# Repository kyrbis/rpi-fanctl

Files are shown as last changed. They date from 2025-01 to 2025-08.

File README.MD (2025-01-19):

This is a replacement pcb for the [ElectroCookie Raspberry Pi 4 Case, Aluminum Mini Tower Case](https://www.amazon.de/dp/B09R6TZCQ8) (or probably [this one](https://www.amazon.de/dp/B09QG349ZL)) to be used with PWM controlled 5V fans like [noctua NF-A4x10 5V PWM, 4-Pin](https://www.amazon.de/dp/B07DXS86G7).

You might also need a [3D printed fan adapter](https://www.thingiverse.com/thing:2995904).

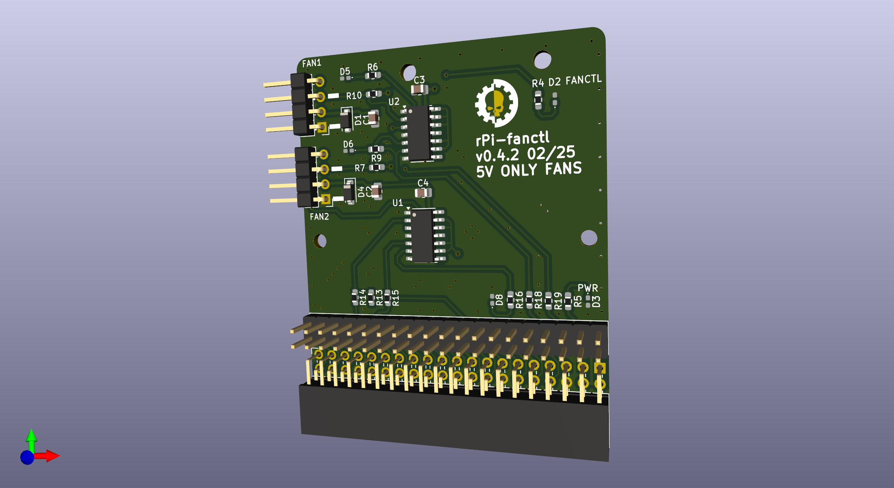
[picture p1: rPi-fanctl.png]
Blessed be the machine.


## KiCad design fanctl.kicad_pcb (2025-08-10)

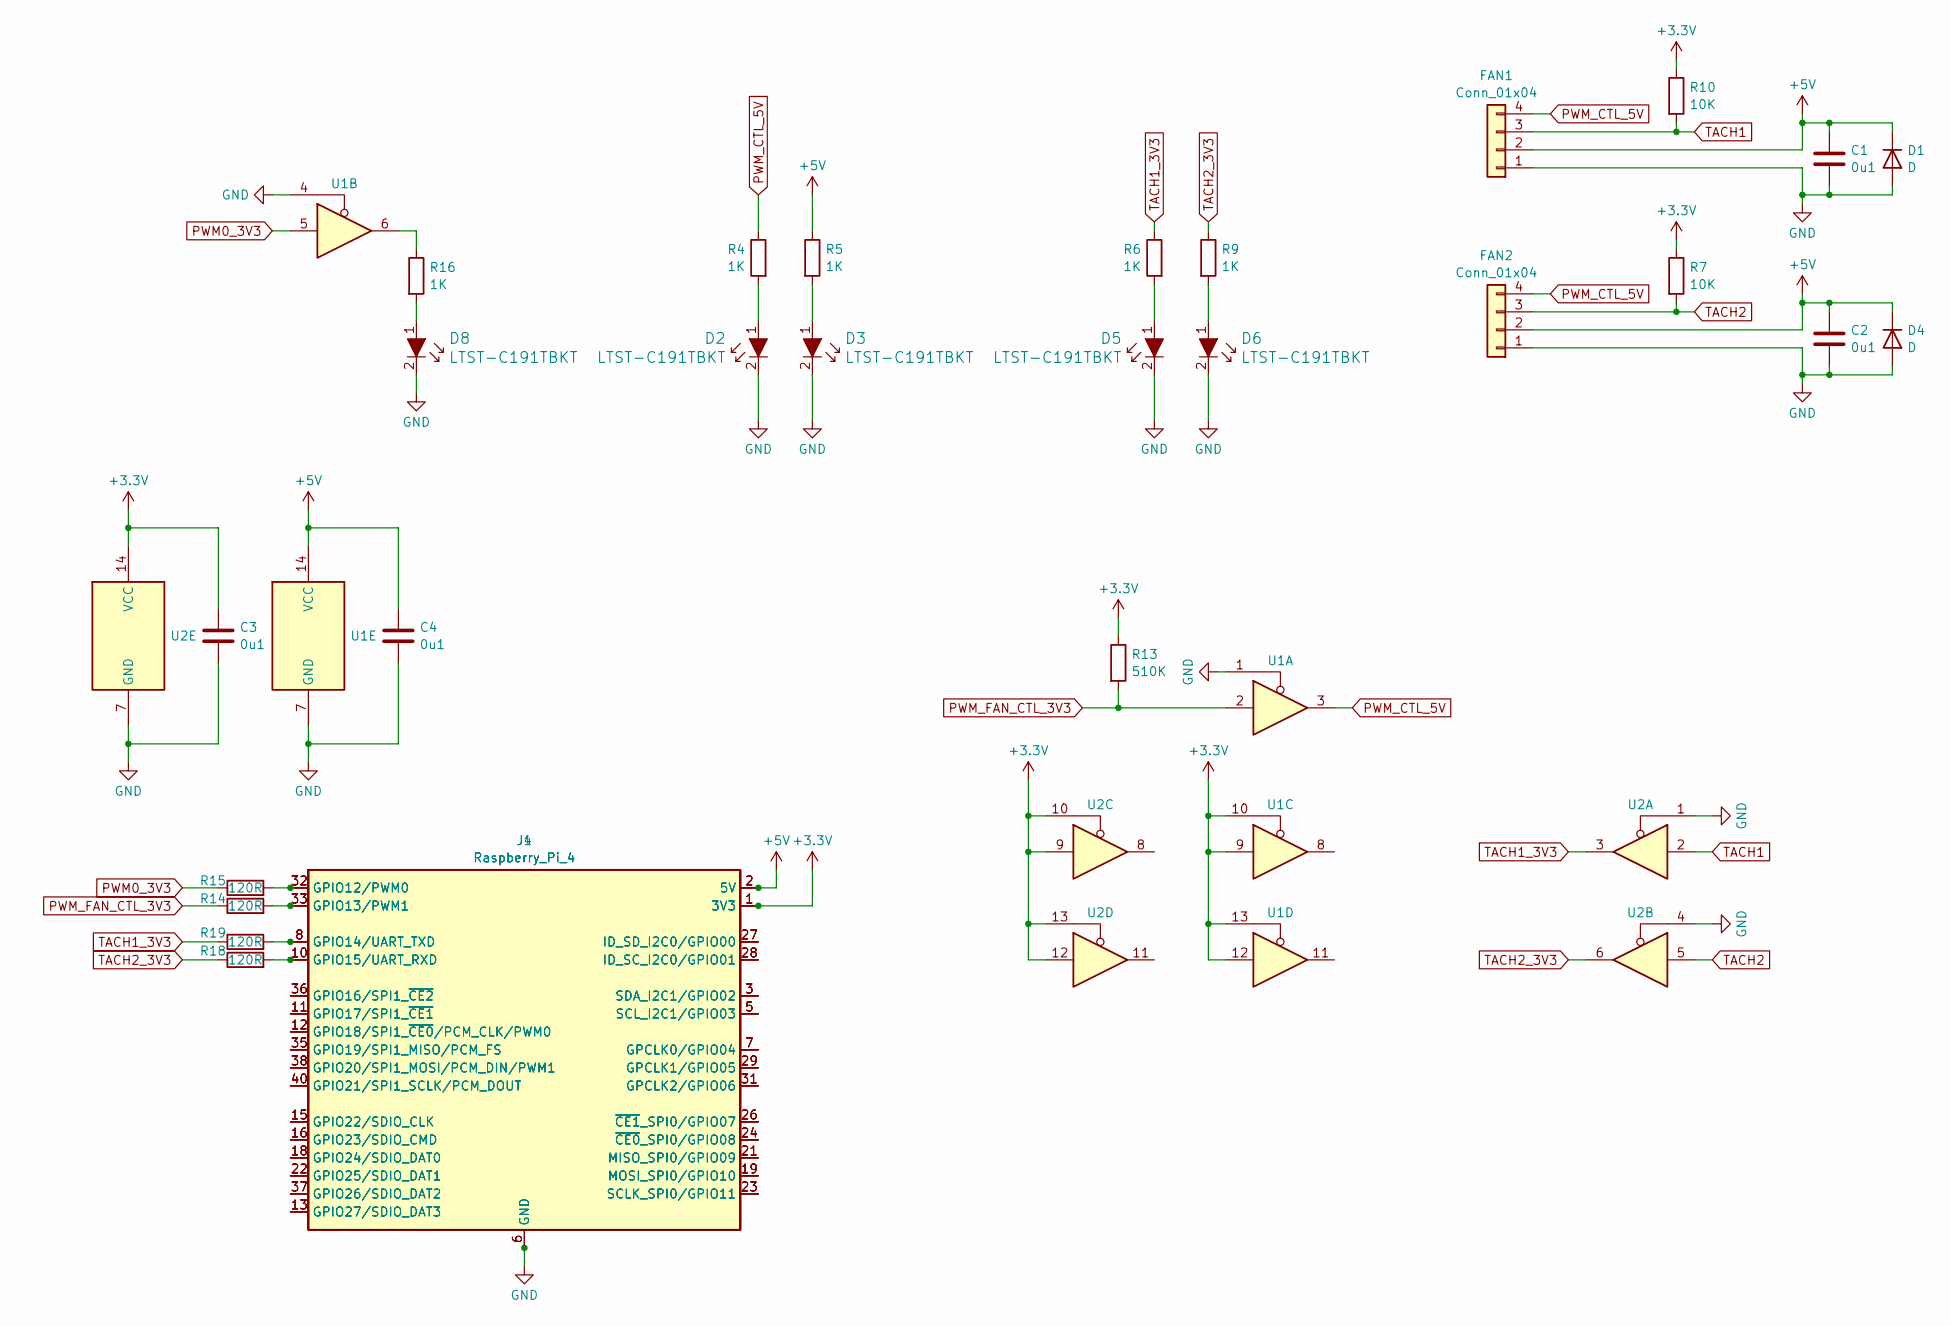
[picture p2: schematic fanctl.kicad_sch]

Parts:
C1, C2, C3, C4: 0u1; C_0805_2012Metric
D1: D; D_SOD-123F
D2, D3, D5, D6, D8: LTST-C191TBKT; D_0402_1005Metric_Pad0.77x0.64mm_HandSolder; MPN LTST-C191TBKT; Digi-Key_PN 160-1647-1-ND
D4: D; D_SOD-123
FAN1, FAN2: Conn_01x04; PinHeader_1x04_P2.54mm_Horizontal
J1: Raspberry_Pi_4; PinSocket_2x20_P2.54mm_Horizontal
J4: Raspberry_Pi_4; PinHeader_2x20_P2.54mm_Vertical
R4, R5, R6, R9, R16: 1K; R_0603_1608Metric_Pad0.98x0.95mm_HandSolder
R7, R10: 10K; R_0603_1608Metric_Pad0.98x0.95mm_HandSolder
R13: 510K; R_0603_1608Metric_Pad0.98x0.95mm_HandSolder
R14, R15, R18, R19: 120R; R_0603_1608Metric_Pad0.98x0.95mm_HandSolder
U1, U2: SN74HCT125DR; SOIC-14_3.9x8.7mm_P1.27mm

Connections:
+3.3V: C3.1, J1.1 (3V3), J1.17 (3V3), J4.1 (3V3), J4.17 (3V3), R7.1, R10.1, R13.1, U1.9, U1.10, U1.12, U1.13, U2.9, U2.10, U2.12, U2.13, U2.14 (VCC)
+5V: C1.1, C2.1, C4.1, D1.1 (K), D4.1 (K), FAN1.2, FAN2.2, J1.2 (5V), J1.4 (5V), J4.2 (5V), J4.4 (5V), R5.1, U1.14 (VCC)
GND: C1.2, C2.2, C3.2, C4.2, D1.2 (A), D2.2, D3.2, D4.2 (A), D5.2, D6.2, D8.2, FAN1.1, FAN2.1, J1.6 (GND), J1.9 (GND), J1.14 (GND), J1.20 (GND), J1.25 (GND), J1.30 (GND), J1.34 (GND), J1.39 (GND), J4.6 (GND), J4.9 (GND), J4.14 (GND), J4.20 (GND), J4.25 (GND), J4.30 (GND), J4.34 (GND), J4.39 (GND), U1.1, U1.4, U1.7 (GND), U2.1, U2.4, U2.7 (GND)
unnamed: D2.1, R4.2
unnamed: D3.1, R5.2
unnamed: D5.1, R6.2
unnamed: D6.1, R9.2
unnamed: D8.1, R16.2
unnamed: J1.7 (GPCLK0/GPIO04), J4.7 (GPCLK0/GPIO04)
unnamed: J1.29 (GPCLK1/GPIO05), J4.29 (GPCLK1/GPIO05)
unnamed: J1.31 (GPCLK2/GPIO06), J4.31 (GPCLK2/GPIO06)
unnamed: J1.32 (GPIO12/PWM0), J4.32 (GPIO12/PWM0), R15.2
unnamed: J1.33 (GPIO13/PWM1), J4.33 (GPIO13/PWM1), R14.2
unnamed: J1.8 (GPIO14/UART_TXD), J4.8 (GPIO14/UART_TXD), R19.2
unnamed: J1.10 (GPIO15/UART_RXD), J4.10 (GPIO15/UART_RXD), R18.2
unnamed: J1.36 (GPIO16/SPI1_~CE2), J4.36 (GPIO16/SPI1_~CE2)
unnamed: J1.11 (GPIO17/SPI1_~CE1), J4.11 (GPIO17/SPI1_~CE1)
unnamed: J1.12 (GPIO18/SPI1_~CE0/PCM_CLK/PWM0), J4.12 (GPIO18/SPI1_~CE0/PCM_CLK/PWM0)
unnamed: J1.35 (GPIO19/SPI1_MISO/PCM_FS), J4.35 (GPIO19/SPI1_MISO/PCM_FS)
unnamed: J1.38 (GPIO20/SPI1_MOSI/PCM_DIN/PWM1), J4.38 (GPIO20/SPI1_MOSI/PCM_DIN/PWM1)
unnamed: J1.40 (GPIO21/SPI1_SCLK/PCM_DOUT), J4.40 (GPIO21/SPI1_SCLK/PCM_DOUT)
unnamed: J1.15 (GPIO22/SDIO_CLK), J4.15 (GPIO22/SDIO_CLK)
unnamed: J1.16 (GPIO23/SDIO_CMD), J4.16 (GPIO23/SDIO_CMD)
unnamed: J1.18 (GPIO24/SDIO_DAT0), J4.18 (GPIO24/SDIO_DAT0)
unnamed: J1.22 (GPIO25/SDIO_DAT1), J4.22 (GPIO25/SDIO_DAT1)
unnamed: J1.37 (GPIO26/SDIO_DAT2), J4.37 (GPIO26/SDIO_DAT2)
unnamed: J1.13 (GPIO27/SDIO_DAT3), J4.13 (GPIO27/SDIO_DAT3)
unnamed: J1.28 (ID_SC_I2C0/GPIO01), J4.28 (ID_SC_I2C0/GPIO01)
unnamed: J1.27 (ID_SD_I2C0/GPIO00), J4.27 (ID_SD_I2C0/GPIO00)
unnamed: J1.21 (MISO_SPI0/GPIO09), J4.21 (MISO_SPI0/GPIO09)
unnamed: J1.19 (MOSI_SPI0/GPIO10), J4.19 (MOSI_SPI0/GPIO10)
unnamed: J1.23 (SCLK_SPI0/GPIO11), J4.23 (SCLK_SPI0/GPIO11)
unnamed: J1.5 (SCL_I2C1/GPIO03), J4.5 (SCL_I2C1/GPIO03)
unnamed: J1.3 (SDA_I2C1/GPIO02), J4.3 (SDA_I2C1/GPIO02)
unnamed: J1.24 (~CE0_SPI0/GPIO08), J4.24 (~CE0_SPI0/GPIO08)
unnamed: J1.26 (~CE1_SPI0/GPIO07), J4.26 (~CE1_SPI0/GPIO07)
unnamed: R16.1, U1.6
PWM0_3V3: R15.1, U1.5
PWM_CTL_5V: FAN1.4, FAN2.4, R4.1, U1.3
PWM_FAN_CTL_3V3: R13.2, R14.1, U1.2
TACH1: FAN1.3, R10.2, U2.2
TACH1_3V3: R6.1, R19.1, U2.3
TACH2: FAN2.3, R7.2, U2.5
TACH2_3V3: R9.1, R18.1, U2.6

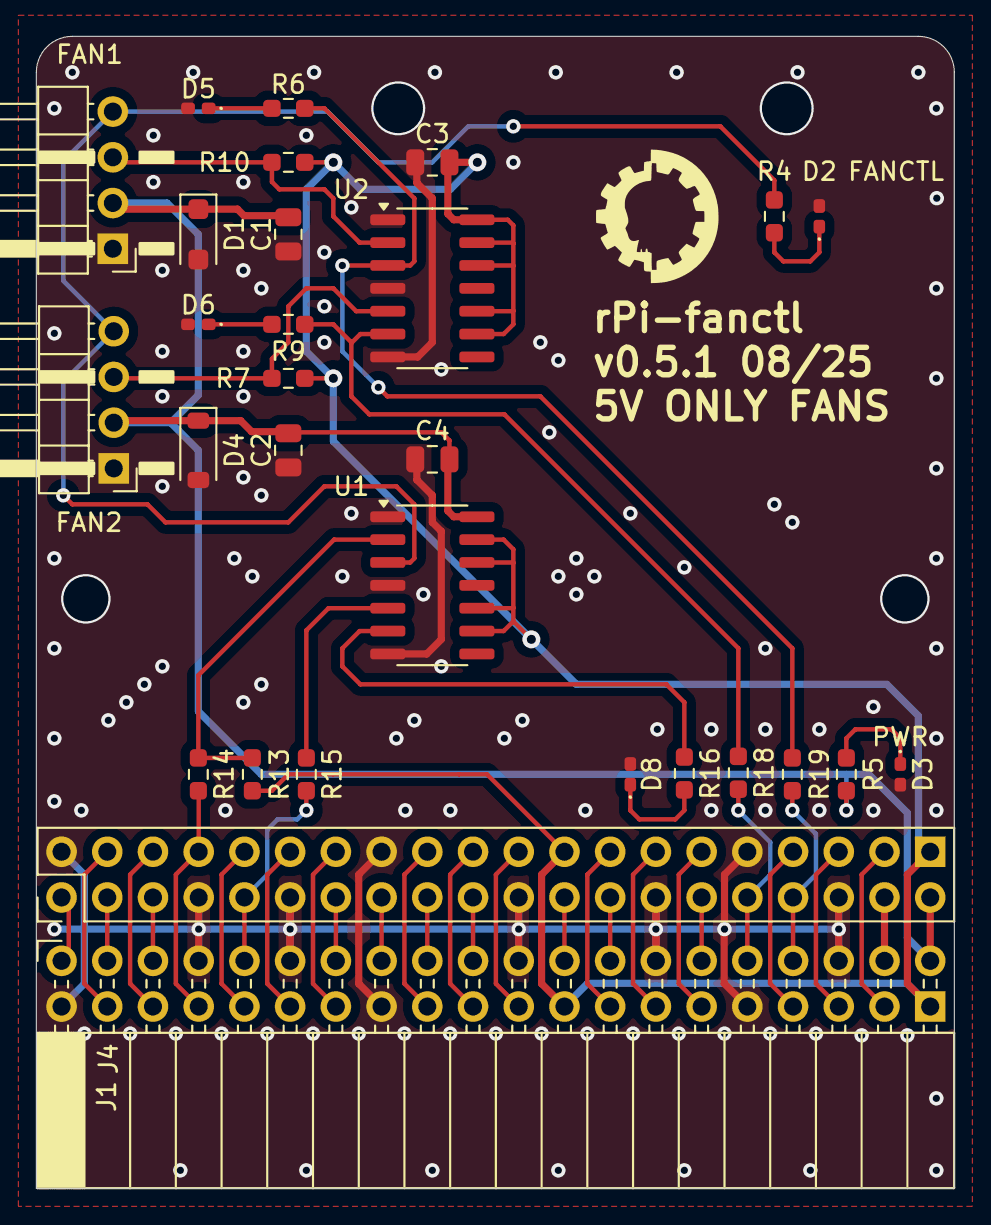
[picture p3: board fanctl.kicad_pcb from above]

Board: 4 copper layers, 51.0 x 64.0 mm, 29 parts (0 on the bottom side), 44 nets.

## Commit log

2025-01-08 added footprints
    [rpi-fan-ctl.kicad_sch]
2025-01-08 some routing progress
    [rpi-fan-ctl.kicad_pcb, rpi-fan-ctl.kicad_sch]
2025-01-08 made all preview connectors angled
    [rpi-fan-ctl.kicad_pcb, rpi-fan-ctl.kicad_sch]
2025-01-14 updated voltage level converter
    [rpi-fan-ctl.kicad_pcb, rpi-fan-ctl.kicad_sch]
2025-01-14 file naming refactor
    [fanctl.kicad_pcb, fanctl.kicad_sch]
2025-01-14 WIP preview sch
    [fanctl.kicad_sch]
2025-01-18 release candidate
    [fanctl.kicad_pcb, fanctl.kicad_sch]
2025-01-18 review feedback
    [fanctl.kicad_pcb]
2025-02-02 rotated pin headers so they are actually right
    [fanctl.kicad_pcb, fanctl.kicad_sch]
2025-02-03 connectors corrected
    [fanctl.kicad_pcb]
2025-02-03 added lines to align fan connector
    [fanctl.kicad_pcb]
2025-03-03 pcb review from @lukekaese
    much thanks!
    [fanctl.kicad_pcb]
2025-08-10 updated connector yet again (previous versions will not work)
    [fanctl.kicad_pcb]
2025-08-10 pcb version bump
    [fanctl.kicad_pcb]
